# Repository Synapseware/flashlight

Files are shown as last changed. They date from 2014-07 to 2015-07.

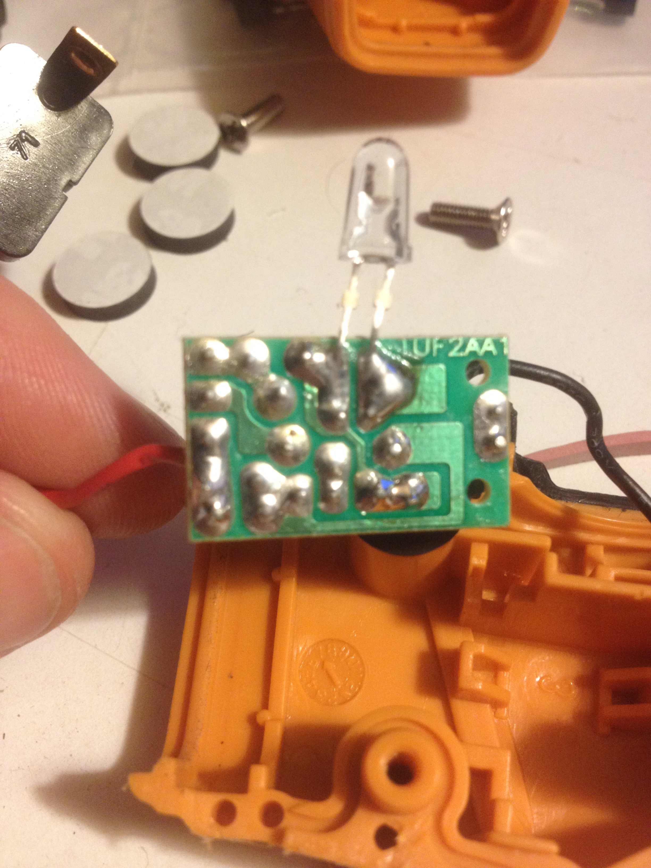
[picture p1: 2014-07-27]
media/IMG_0708.JPG

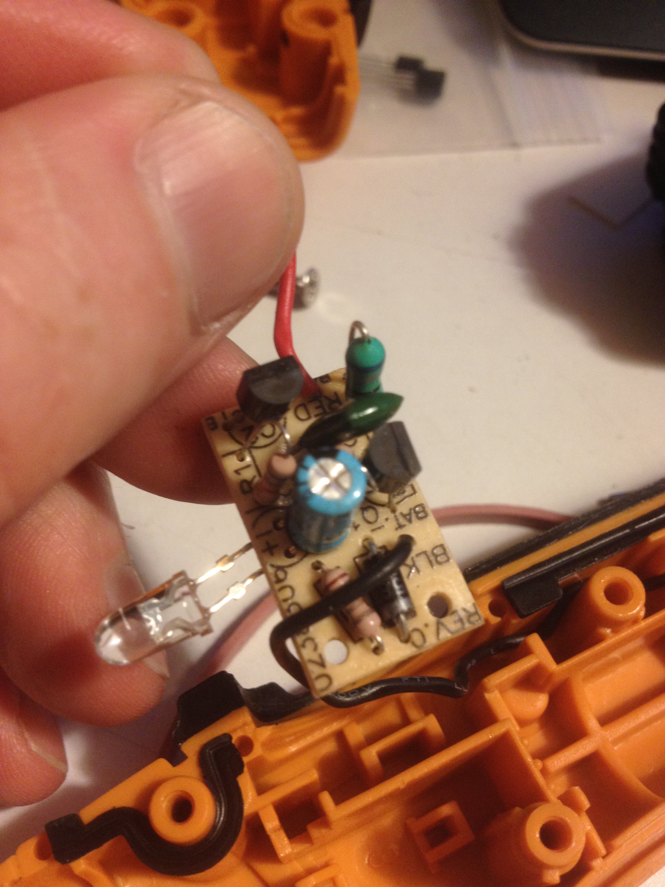
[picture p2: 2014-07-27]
media/IMG_0709.JPG

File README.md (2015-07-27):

flashlight
==========

## about
Uses 2xAA batteries powering an LTC3490 constant current LED driver.  This LED driver is an efficient, compact design and relatively easy to setup.

## board
* Dimensions are 15mm x 25 mm
  * LED is normal 2 lead type, white, mounted on the trace side
* Center of LED is about center of the board, so 12.5mm in
* Constant-current circuit is an [LTC3490](http://www.linear.com/product/LTC3490).

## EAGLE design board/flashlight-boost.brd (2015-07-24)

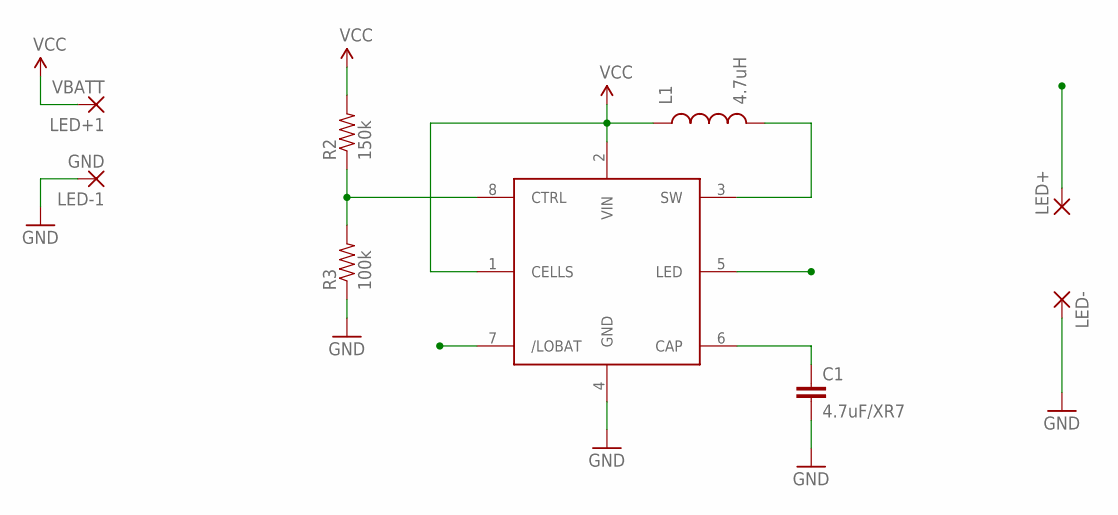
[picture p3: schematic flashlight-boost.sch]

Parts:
C1: 4.7uF/XR7; 1206
L1: 4.7uH; 1210
LED+: 2,54/1,0
LED+1: VBATT; 2,54/1,0
LED-: 2,54/1,0
LED-1: GND; 2,54/1,0
R2: 150k; 0603-RES
R3: 100k; 0603-RES
U$1: LTC3490NSOIC-8; NSOIC-8

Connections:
GND: C1.2, LED-.1, LED-1.1, R3.1, U$1.4 (GND)
LED: LED+.1, U$1.5 (LED)
unnamed: L1.2, U$1.3 (SW)
unnamed: C1.1, U$1.6 (CAP)
unnamed: R2.1, R3.2, U$1.8 (CTRL)
VCC: L1.1, LED+1.1, R2.2, U$1.1 (CELLS), U$1.2 (VIN)

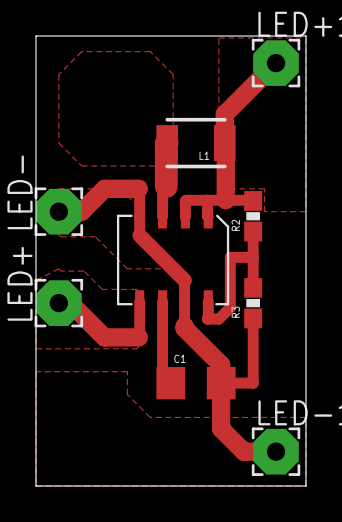
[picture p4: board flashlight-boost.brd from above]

Board: 2 copper layers, 15.0 x 25.0 mm, 9 parts (0 on the bottom side), 6 nets.

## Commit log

2014-07-27 Adding new flashlight project - board layout
    [flashlight-boost.brd, flashlight-boost.sch]
2014-07-27 Adding photos of old board
2014-07-27 removing constant current LED driver since the current sense resistor for it is the same value as the LED series resistor
    [flashlight-boost.brd, flashlight-boost.sch]
2014-07-29 misc updates
    [flashlight-boost.brd, flashlight-boost.sch]
2014-08-02 Converting driver board to use LTC3490 part
    [flashlight-boost.brd, flashlight-boost.sch]
2014-08-16 Final board layout
    [flashlight-boost.brd]
2015-07-24 Fixing voltage divider.
    The voltage divider was setup to yield a control voltage of 0.6v which for a 2.4v input sets up the LED driver for a driver current of just over 25mA. The drive current should be between 80mA and 100mA. Lowering R1 in the divider to somewhere between 178k and 150k will do just that.
    [flashlight-boost.brd, flashlight-boost.sch]

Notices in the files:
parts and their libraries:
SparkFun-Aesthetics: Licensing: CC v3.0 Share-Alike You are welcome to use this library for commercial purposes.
